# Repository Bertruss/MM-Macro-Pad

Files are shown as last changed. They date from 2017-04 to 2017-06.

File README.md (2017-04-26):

# MM Macro Pad
Code and various design artifacts for build of a key matrix, for use as a macro-pad. Microcontroller used is the *Teensy-LC*. In many ways this is a very simple project, but the goal is not to break new ground so much as it is to learn new skills. Code is currently using the teensyduino libraries for ease of implementation, but I'm hopeful to eventually try the more "hands on" approach, with less reliance on the arduino ide and teensyduino libraries.

## Current features
- option for button cooldown
- option for longhold function 
  - e.g. a held button repeatedly executes the buttons associated function
- supports button assignments for: 
  - media key functions
  - function keys  
  - arrow keys
  - "joystick" buttons (convenient for software macros)
  - all typical keyboard key assignments
- support for scripting
- can be adjusted to any number of rows or columns
- Implementation of animations and controls for LED lighting

## additional design goals 
- multiple modes for macros and functions.

## Hardware
- Hardware folder contains design files for the layout of the keypad.
	- .stl model for main housing  
	- parts manifest, with available sources and cost estimation

## Instructions for compilation & custom configuration as well as
## release source can be found in the Keymat folder.

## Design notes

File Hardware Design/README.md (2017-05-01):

# Parts Manifest:
 
Teensy-LC w/ header pins, $17
 - Source: Amazon
  - Though https://www.pjrc.com might be better. I would see if shipping makes the difference for you. 
	
Prototyping PCB, 20c	
 - Source: local DIY supplier
	
Set of 9 transluscent keycaps (WASD, ARROWS, ESC), $6.99
 - Source: Amazon. 
  - The WASD ARROW ESC bundle is probably the cheapest way to buy such a small number of caps. (<$1 per cap)	
  - not all sculpted for the same row, but the bottom & middle row will be consistent.
  - alternatively you can buy individual or small packs of keycaps from pimpmykeyboard.com 

15 1N914 Diodes, 75c
 - Source: local DIY supplier
  - low tolerance, but anything more isn't needed
  - bought spares, only 9 needed

10 Cherry MX clear switches $8.50
 - Source: https://mechanicalkeyboards.com/
	- bought 30 switches with a friend to bring the price down
	- Gateron switches come highly recommended as Cherry MX clones, 
	  and are in many cases cheaper 

100 3mm flangeless diffuse white LED's (included 100 500ohm resistors) $4.50
 - Source: Ebay
	- There are certainly other options, this was the cheapest I found

# Making an enclosure
The easiest way to create an enclosure should be to use the provided model files and 3D print them, 
but I realize this might not be feasible for everyone. Alternatively, following resources can be used 
to create a faceplate file which can be used to cut an appropriate front plate to hold the switches. 
I have provided a basic vector file template for a 3x3 switch pad.   

## Face-Plate template resources
 - Key Layout generator
    - http://www.keyboard-layout-editor.com/#/
 - Faceplate vector file generator
	- http://builder.swillkb.com/
 - Vector files can be opened with the free and open source program Inkscape, available here
	- https://inkscape.org/

## Enclosure Model
 - The enclosure STL and 123D files are my attempts at an easily 3d-printable enclosure.  
 - The provided model has a length and width of 3 x 3.5 inches

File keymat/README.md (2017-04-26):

# Extensible Button Matrix using a Teensy microcontroller

## Features

### Debounce

 - Cleans input of noise that occurs from switch depressing.

### Button cooldown

  - Can help prevent accidental double activation of a key function by way of rapid double tap.
  - Independent values for each button, adjusted via the associated value in the ```cooldown_time``` array
  - When you disable the cooldown timer, button presses are still only registered once assuming it passes the debounce check.

### Longhold

  - You know when you hold a button for more than a second it just acts like continuous presses. that thing.
  - Independent values for each button, adjusted via the associated value in the ```longhold_time``` array
  - Disabled by being set to 0
  - Not blocked by cooldown
  
### Fully rebindable

Each key is read as their address, that address is then mapped to a case in the keymap function, which 
essentially executes as a script. For a full range of what can be put in these scripts, links to the 
documentation from PJRC (the teensyduino libs) and Arduino regarding keyboard communications and the 
signals that can be sent from the teensy can be found at the bottom of this document.
              
### Extensible

Many parts will have to be manually adjusted, but I have tried to make it as painless
as possible to make your own matrix with however many rows and columns as you might want. 
Admittedly, it's still a huge hassle.

note: all time is counted in ms, or 1/1000 of a second

You can create as many rows and columns as you'd like, but this is how it is configured by default
The number on each key in the map below marks its address in the buffer as well as it's signifier in the operation queue

                  0    1    2      
               |----|----|----|
             0 | 0  | 1  | 2  |
               |----|----|----|
             1 | 3  | 4  | 5  |
               |----|----|----|
             2 | 6  | 7  | 8  |
               |----|----|----|

### Limited PWM LED animations and profiles for backlighting
 
Anyone truly wanting impressive lighting effects will likely want to use a seperate IC made for PWM LED control as the teensyLC has 
a limited number of PWM pins. The current implementation of lighting animations and controls treats each row of
switches as single lighting entities (being wired in parallel to a single PWM pin), limiting the animation's complexity significantly.
The implemented animations are mostly soft flicker, and various profiles for sinusoidal pulsing. Because the profiles are so specific to my build, 
I've left this code out of the main build. The build with the lighting implementation can be found in the Keymat_Light subfolder in this 
directory. 

## Instructions For Use
In order to use this code with your teensy, you must:

1.  Have the Arduino IDE installed
2.  Have the Teensyduino libraries installed
3.  Place the LCqueue folder from "libraries" to your Arduino install's "libraries" folder
4.  Open the src file in the Arduino IDE and mouse over the Tools tab
  * make sure "Board" says whichever teensy you are using.
  * "USB Type" needs to be "KeyBoard + Mouse + Joystick"
5.  go to Sketch > Include Library > LCqueue	(this will be under "contributed libraries")
6.  At this point, the code can be compiled.
  * There are currently instructions in file for how to customize the software, which you can go through.

## Important Links and resources
[Teensyduino](http://www.pjrc.com/teensy/td_download.html) & [Arduino IDE](https://www.arduino.cc/en/Main/Software) (May need to be a legacy release for teensyduino compatibility, check the download and install instructions on PJRC for details)

[AutoHotKey](http://ahkscript.org/) (for software macro's. It's really good, and more flexible than what can be implemented from hardware.)

Guides on PJRC for the [Keyboard](http://www.pjrc.com/teensy/td_keyboard.html), [Mouse](http://www.pjrc.com/teensy/td_mouse.html) and [Joystick](http://www.pjrc.com/teensy/td_joystick.html) libraries

[Forum thread about Media Key Codes](https://forum.pjrc.com/threads/34074-Keyboard-Media-Keys-now-%28hopefully%29-Windows-compatible)

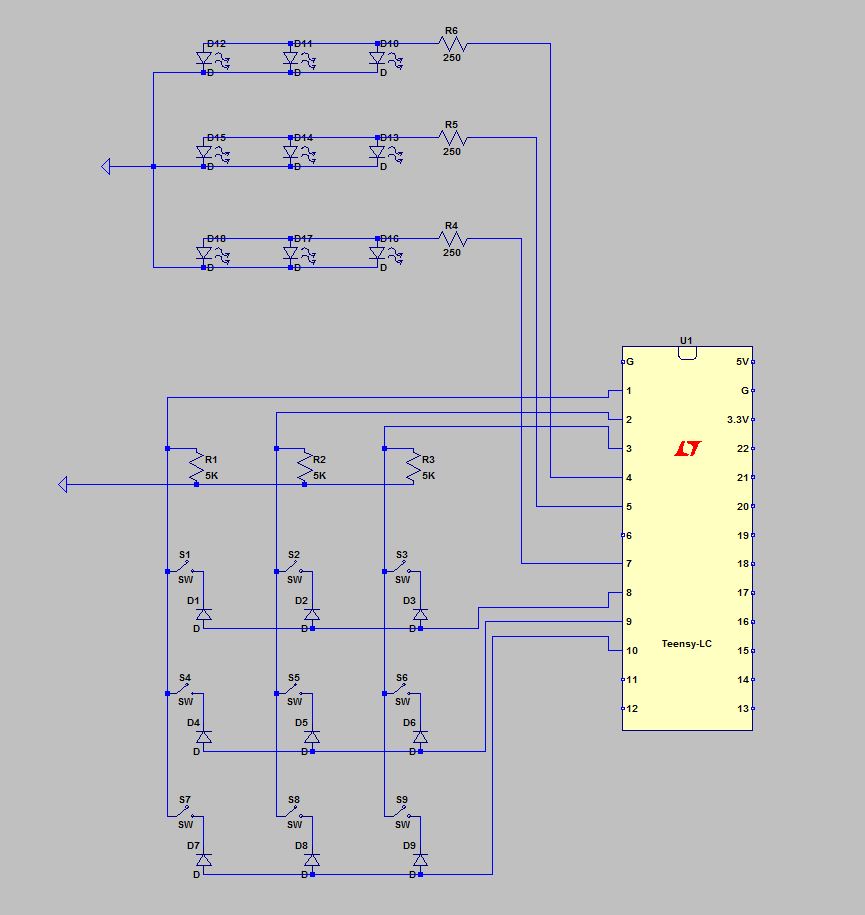
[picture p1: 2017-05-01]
Hardware Design/Circuit Design/Key Matrix with LEDs.JPG

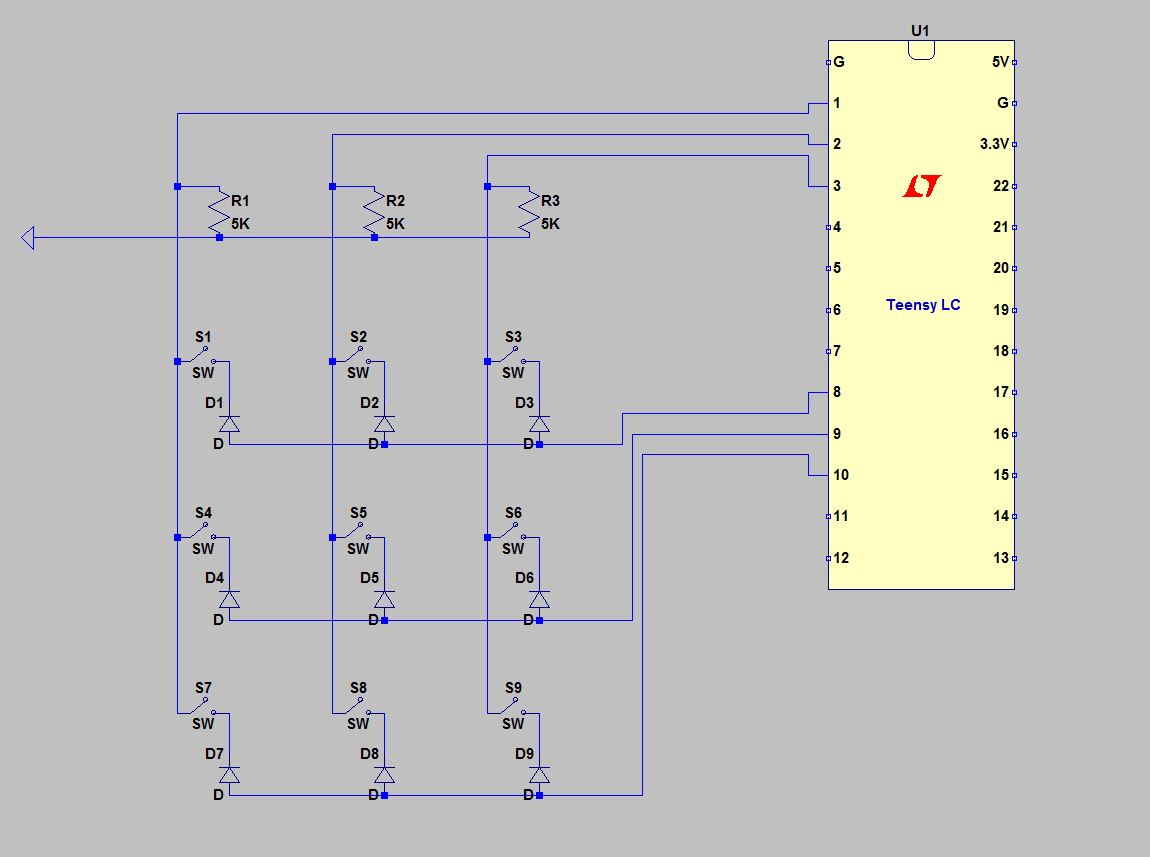
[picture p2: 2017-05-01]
Hardware Design/Circuit Design/Key Matrix.JPG

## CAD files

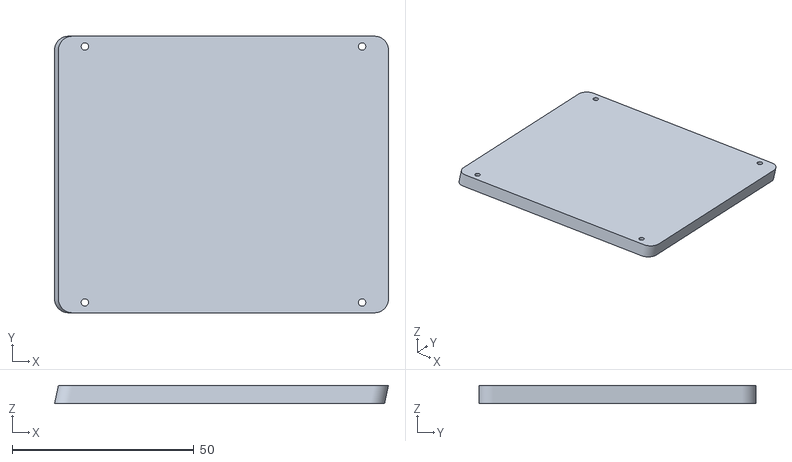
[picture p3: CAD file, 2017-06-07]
Hardware Design/Enclosure and Faceplate Designs/stl files/bottom_plate.stl
92.0 x 76.2 x 5.09

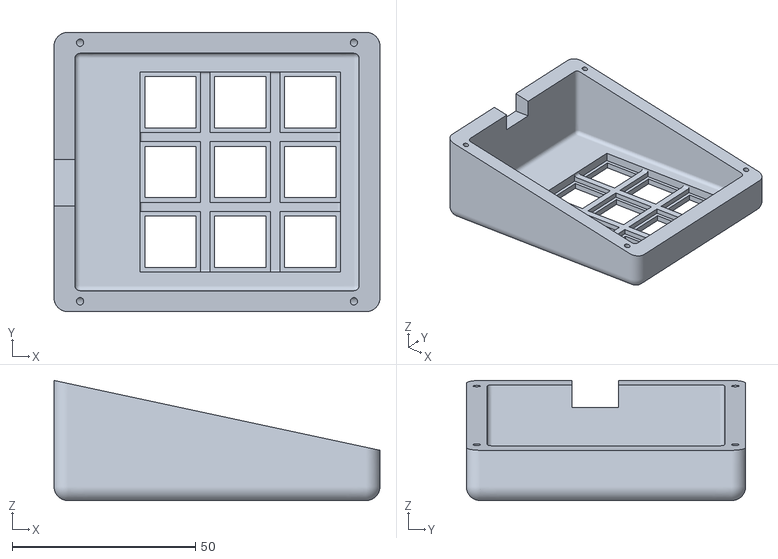
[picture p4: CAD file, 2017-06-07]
Hardware Design/Enclosure and Faceplate Designs/stl files/enclosure.stl
88.9 x 76.2 x 32.8

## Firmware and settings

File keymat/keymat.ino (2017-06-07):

/* Extensible Button Matrix using a Teensy microcontroller
   author: Michael Hautman
   year: 2016
*/
#include <LCqueue.h>

// `a` is the code for the key press you wish to pass.
#define STANDARD_KEY_PRESS(a) Keyboard.press(a); Keyboard.release(a);

// `a` is the number of the joystick button you wish to transmit a
// keypress of. The delay is necessary for the press to be registered. 
#define JOYSTICK_BUTTON_PRESS(a) Joystick.button(a, 1); delay(50); Joystick.button(a, 0);


//function prototypes
void KeyMap(int address);
bool softModCheck(int I);
int buttonaddr(int rownum, int colnum);
void debounce(int rownum, int colnum);
bool checkLongHold(unsigned long button_cooldown_time,  unsigned long button_confirmed_state_change_time, int address);
bool checkExceptionTimers(int address);
void rowSet(int rowIn);
void scan();
void genOutputBuffer();
void executeBuffer();

/*
 ***********************************
 ****** CUSTOMIZABLE ELEMENTS*******
 ***********************************
*/

/*
   NOTE:
   Button numbering, referred to often as "address" within the comments, is very simple 
   but important to understanding the code. buttons are numbered firstly left to right then wrapping 
   to the next row, the same order in which you would read words on a page. It is mentioned elsewhere, 
   but just to re-iterate, all time is in is ms.
*/

// This setting controls the number of rows the teensy expects
#define NUM_ROWS 3

// This setting controls the number of columns the teensy expects
#define NUM_COLUMNS 3

// Number of buttons
#define BUTTONS (NUM_ROWS * NUM_COLUMNS)

// Array that holds debounced button value
int button_buff[BUTTONS];

// Pin Assignment for the columns and rows of the key matrix 
// You must assign as many pins as there are columns and rows
const int col[NUM_COLUMNS] PROGMEM = {0,1,2}; //these are the pins that are read
const int row[NUM_ROWS] PROGMEM = {8, 9, 10}; //these are the pins that are set

/* BUTTON COOLDOWN
   This array is where you would set the cooldown time for each button.
   This is useful if there are any functions that you want to ensure can't have an accidental double activation.
   NOTE: These numbers are in ms, the associated button's identifier is commented next to each cooldown #.
*/
const unsigned long cooldown_time[] PROGMEM = {
  0,  // 0
  0,  // 1
  0,  // 2
  0,  // 3
  0,  // 4
  0,  // 5
  0,  // 6
  0,  // 7
  0   // 8
  // Needs to be extended to the correct number of buttons if more columns or rows are added
};

/* LONGHOLD
   This is where you set the length of time to "longhold state" for each key, where if you've been holding down a button for
   longer than the set longhold time for that button, the button's associated operation runs repeatedly. This mirrors what you
   expect a normal keyboard to do with a button for a single ascii character. I wouldn't recommend having this enabled for anything
   particularly complicated.

   NOTE: These numbers are in ms, the associated button's identifier is commented next to each longhold #.

   NOTE #2: Longhold is conditionally blocked by cooldown. e.g. a button with a cooldown of 2 seconds and a longhold
   of 1 second will still reach longhold state in 1 second. cooldown only applies to buttons that have been
   pressed and then released. In the case where a button *has* been pressed and then released, the time to 
   longhold state for the next button press will be measured from the first registered activation, 
   e.g. after cooldown has finished. This was an arbitrary decision, but mixing these two features generally 
   yields dumb results anyway. 
*/

const unsigned long longholdt[] PROGMEM = {
  0,  // 0
  0,  // 1
  0,  // 2
  500,  // 3
  0,  // 4
  500,  // 5
  0,  // 6
  0,  // 7
  0   // 8
  //Needs to be extended to the correct number of keys if more columns or rows are added
};

const unsigned long longhold_active_t PROGMEM = 200;//controls how frequently the long hold operation registers an activation

/* BUTTON MACRO SETTINGS   -[DEFAULT CONFIGURATION]-
   This function handles mapping button input to desired keypad output.
   The keypad supports basic scripting, "binds", media key functionality,
   as well as "blank" joystick buttons which can be easily mapped into more
   complex scripts through software such as AutoHotKey (which I highly recommend).
   I have tried to make the media Key functionality cleaner to implement with the
   "STANDARD_KEY_PRESS" macro, which sends a single press and release. 

   Each case # corresponds to the button's identifier in the matrix, and the script or what-have-you that you'd like to
   have execute goes after the desired "case # :" but before the "break;".
*/

void KeyMap(int address) {
  // hardModCheck();
  switch (address) {
    case 0 : // Previous Track
      STANDARD_KEY_PRESS(KEY_MEDIA_PREV_TRACK);
      
      break;
    case 1 : // Play/Pause
      STANDARD_KEY_PRESS(KEY_MEDIA_PLAY_PAUSE);
      
      break;
    case 2 : // Next Track
      STANDARD_KEY_PRESS(KEY_MEDIA_NEXT_TRACK);
      
      break;
    case 3 : // Volume Down
      STANDARD_KEY_PRESS(KEY_MEDIA_VOLUME_DEC);
      
      break;
    case 4 : // Mute
      STANDARD_KEY_PRESS(KEY_MEDIA_MUTE);
      
      break;
    case 5 : // Volume Up
      STANDARD_KEY_PRESS(KEY_MEDIA_VOLUME_INC);
       
      break;
    case 6 : //joystick 1
      JOYSTICK_BUTTON_PRESS(1);
 
      break;
    case 7 : //joystick 2
      JOYSTICK_BUTTON_PRESS(2);
      
      break;
    case 8 : //joystick 3
      JOYSTICK_BUTTON_PRESS(3);
 
      break;
      
    // If you add more rows or columns, more cases need to be added
    
    // *script stereotype*
    /*    
           case # :
              YOUR CODE HERE;
    
            break;
    */
    default :
      break;
  }
}

// Soft Mod check is a simple function to see if a given button is depressed.
// Usefull for having scripted modifiers
bool softModCheck(int I) {
  if(button_buff[I] == 1){
    return true;
  } else {
    return false;
  }
}

/*
 ******************************************
 ****** NON - CUSTOMIZABLE ELEMENTS *******
 ******************************************
*/

// Arrays for button debouncing
int button_lastState[BUTTONS];
unsigned long confirm_timer[BUTTONS];  // Last moment in time when the state of the button was confirmed via debounce
unsigned long debounce_timer[BUTTONS]; // Last moment in time when the state of the button was directly read to have changed
const unsigned long delayt = 10;       // How long a button needs to be depressed in order to be confirmed via debounce, in ms

// Output/operation queue
LCqueue *outputBuffer;

// Cooldown time marker array
unsigned long cooldown_timer[BUTTONS];

// Longhold time marker array
unsigned long longhold_timer[BUTTONS];

// Given col and row, returns button address
int buttonaddr(int rownum, int colnum) {
  return (NUM_ROWS * rownum) + (colnum);
}

// Debouncing pin reader, prevents rapid on/off switching or registering multiple button presses due to switch noise.
void debounce(int rownum, int colnum) {
  int address = buttonaddr(rownum, colnum);

  // Current state of pin assigned to pinRead
  int readPin = digitalRead(col[colnum]);

  // If pin state changes, reset debounce time marker to current time
  if (readPin != button_lastState[address]) {
    debounce_timer[address] = millis();
  }

  // If pin has not changed state for longer than the debounce delay (delayt), then commit current state to button_buff
  if ((millis() - debounce_timer[address]) > delayt && readPin != button_buff[address]) {
    confirm_timer[address] = millis();
    button_buff[address] = readPin;
  }
  button_lastState[address] = readPin;
}

// Checks whether the button at the given address has reached longhold state
bool checkLongHold(unsigned long button_cooldown_time,  unsigned long button_confirmed_state_change_time, int address) {
  /*
     ">=" is used because it happens on a shorter than ms scale. logically, if they're equal, cooldown reset had to happen
      after the state change reset because of the order of the flow. This next part is broken up to be
      easier to explain and read.
  */
  if (button_cooldown_time >= button_confirmed_state_change_time // If the last time buttonstate changed was before the last time
      && longholdt[address] != 0) {                              // the cooldown timer was reset, and the address has a longhold value set,
                                                                 // continues.
    if ((millis() - button_cooldown_time) > longholdt[address]) { // If the button has been held down long enough for a long hold mode activation

      if ((millis() - longhold_timer[address]) > longhold_active_t) { // This is another timer checker used to limit how fast 
                                                                      // the longhold state registers activations
        longhold_timer[address] = millis();
        return true;
      }
    }
  }
  return false;
}


// Multistage checker that handles cooldown and longhold functionality logic
bool checkExceptionTimers(int address) { // Returns true if cooldown timer is exceeded, or if a longhold state activation is reached
  unsigned long button_cooldown_time = cooldown_timer[address];
  unsigned long button_confirmed_state_change_time = confirm_timer[address];
  if (checkLongHold(button_cooldown_time, button_confirmed_state_change_time, address)) {
    return true;
  }
  else if (cooldown_time[address] != 0                                       // If the button has a cooldown timer set
           && button_confirmed_state_change_time > button_cooldown_time      // and the last time the buttons confirmed state change is sooner
           && (millis() - button_cooldown_time) > cooldown_time[address] ) { // than the last time button cooldown was reset and cooldown timer is exceeded
    cooldown_timer[address] = millis();                                      // resets timer, returns true
    return true;
  }
  else if (button_confirmed_state_change_time > button_cooldown_time) { // Makes sure that if the cooldown is disabled, one button
    cooldown_timer[address] = millis();                                 // press still only registers once unless longhold is exceeded
    return true;
  }
  else {
    return false; // All else return false.
  }
}

// Sets chosen row high and all others low
void rowSet(int rowIn) {
  for (int cnt = 0; cnt < NUM_ROWS; cnt++) {
    if (cnt == rowIn) {
      digitalWrite(row[cnt], HIGH);
    }
    else {
      digitalWrite(row[cnt], LOW);
    }
  }
}


// Checks every button in the matrix, runs "debounce" on it
void scan() {
  for (int rownum = 0; rownum < NUM_ROWS; rownum++) {      // Increments rownum
    rowSet(rownum);                                               // and sets the row with that number to HIGH.
    for (int colnum = 0; colnum < NUM_COLUMNS; colnum++) { // Increments colnum
      debounce(rownum, colnum);                                   // and runs "debounce" on that column
    }
  }
}

/* Reads the current button state as determined via debounced button matrix scan,
   and then makes sure the press is registerable (has no withstanding cooldown,
   if it's exceeded longhold time, or if the output buffer has reached 100, an arbitrarily determined limit).
*/
void genOutputBuffer() {
  for (int address = 0; address < BUTTONS; address++) {
    int state = button_buff[address];
    if (state == HIGH && checkExceptionTimers(address) && (count(outputBuffer) < 100)) {
      push(outputBuffer, address);
    }
  }
}

// Executes operations described by the outputBuffer.
void executeBuffer() {
  if (!isEmpty(outputBuffer)) { // If the queue is empty, does nothing
    KeyMap(pop(outputBuffer));
  }
}

// Runs once before loop()
void setup() {
  //button matrix instantiation
  for (int cnt = 0; cnt < NUM_ROWS; cnt++) {    // Instantiates every pin in row[] to OUTPUT
    pinMode(row[cnt], OUTPUT);
  }
  for (int cnt = 0; cnt < NUM_COLUMNS; cnt++) { // Instantiates every pin in col[] to INPUT_PULLUP
    pinMode(col[cnt], INPUT);
  }
  outputBuffer = new_queue();               // Allocating memory for queue
}

// Main Loop, which runs continuously
void loop() {
  scan();
  genOutputBuffer();
  executeBuffer();
}

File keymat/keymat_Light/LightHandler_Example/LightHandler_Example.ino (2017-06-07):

#include <LightHandler.h>
//demo


const int NumLEDS = 6;//number of pins used
const int LEDpin[NumLEDS] = {11,10,9,6,5,3};//PWM pin numbers

light* Lights = new light[NumLEDS]; //instantiating a array of 'light' structures to be manipulated by the lighthandler object
LightHandler lightcontrol; //allocates memory for lighthandler object 'lightcontrol'

void setup() {
  //constructing instance of lighthandler
  lightcontrol = LightHandler(LEDpin, Lights, NumLEDS); 

  //sets the current animation to "blip", which does random soft flashes. 
  lightcontrol.setLightPreset(BLIP);
  
  lightcontrol.setMidIntensity(0); //sets the base brightness of all available objects. 
  lightcontrol.setRange(10); //sets tha max variance from the base brightness executed by the light animations within LightHandler
 
}

void loop() {
  lightcontrol.execute();
}

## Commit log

2016-11-02 initial commit of empty teensy control program
2016-11-02 Added arduino file for testing hardware and code snippets. Wrote quick 'pushbutton activated led' program in the testing file. it works. progress :).
2016-11-08 Wrote 7 segment display driver program as a bit of a laugh
2016-11-14 Rewrote matrixtest for button debouncing. simplified code.
2016-11-15 Added parts manifest to HW design Readme. Implemented longhold and button cooldown. tried to implement an output queue, but apparently the teensy-LC doesn't support FIFO datatypes (?). will have to e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
2017-02-05 formatting of comments, adding clarity. reconsidering certain design decisions.
    [enclosure.stl]
2017-04-26 added code for LED light animations, updated readmes
2017-04-29 updating model files
    [enclosure.stl]
2017-04-30 added backplate model to .stl and .123d files
    [enclosure.stl]
2017-04-30 added bottom plate to designs
2017-04-30 fixing errors from last commit. stopped teensy from using INPUT_PULLUP setting on inputs.
    [keymat.ino, keymat_Light.ino]
2017-05-01 added circuit layout, cleaned up file structure
    [enclosure.stl]
2017-05-01 seperating bottom plate and enclosure into 2 design files.
    [bottom_plate.stl, enclosure.stl]
